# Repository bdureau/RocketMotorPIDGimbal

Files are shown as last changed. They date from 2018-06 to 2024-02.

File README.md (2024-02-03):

# RocketMotorPIDGimbal (firmware)
This is yet again another attempt to fly a model rocket without fins using long burn motors. The following repository is the firmware for the board.
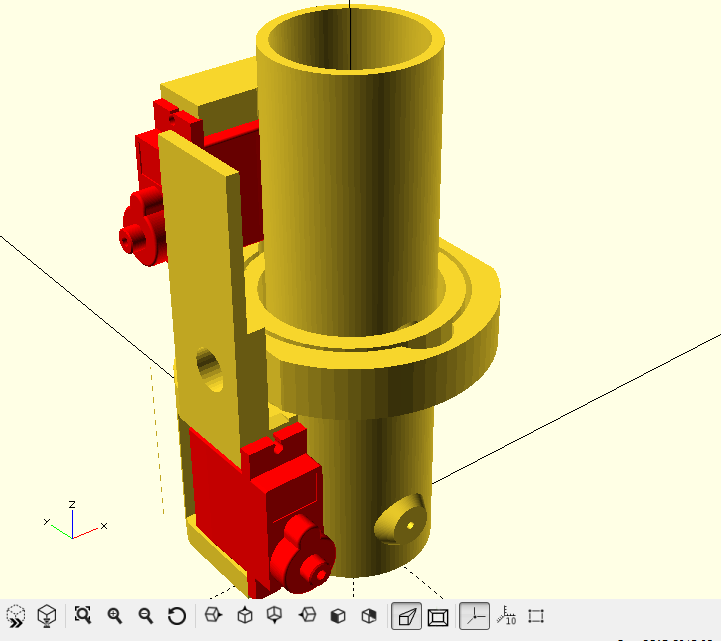
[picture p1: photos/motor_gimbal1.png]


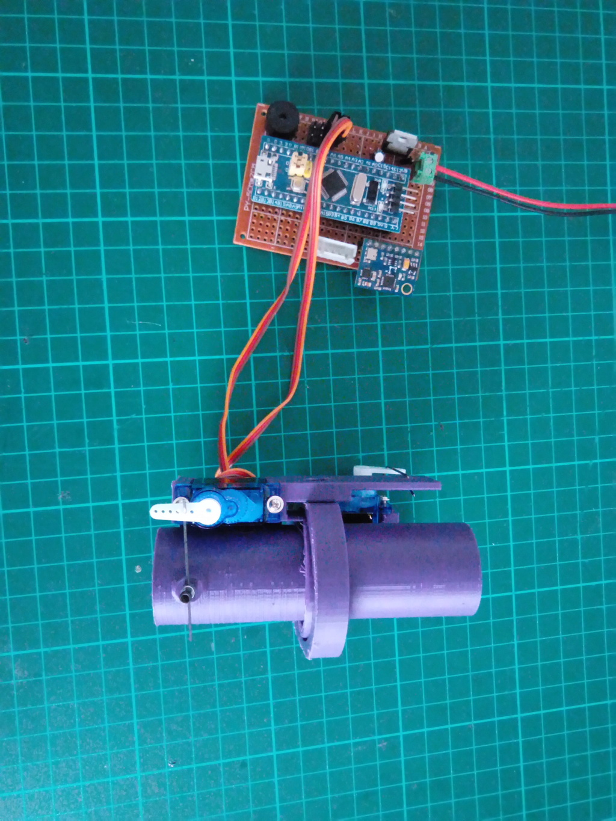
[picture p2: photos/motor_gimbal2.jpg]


I am using the Arduino PID library an STM32F103C board (you can use an arduino Nano) and a 3D printer to print the 24mm motor gimbal
It uses a bluetooth module (HC-05, HC-06 etc ...)to communicate with an Android device



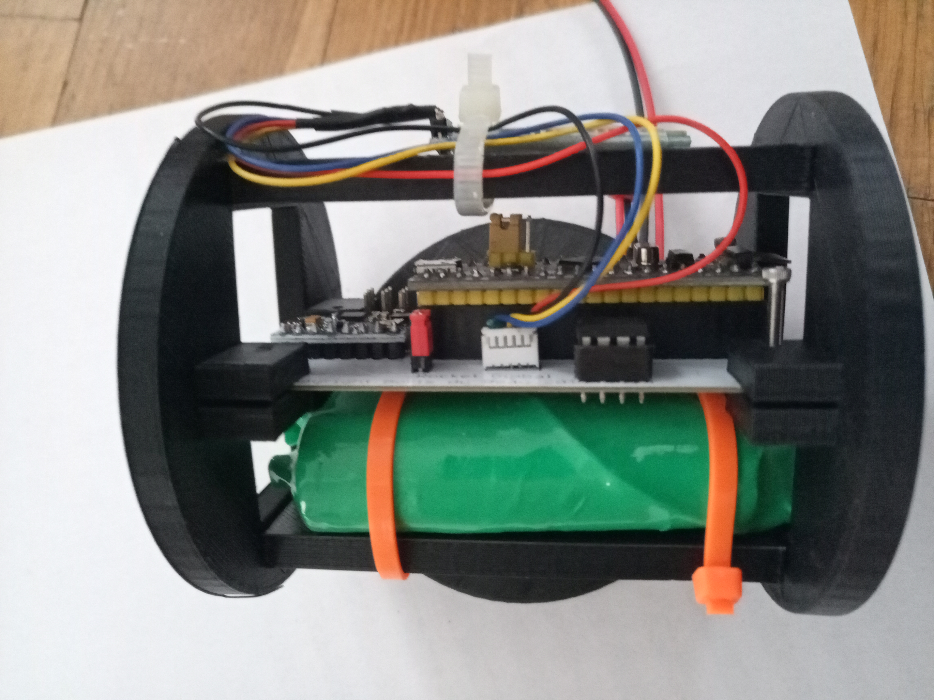
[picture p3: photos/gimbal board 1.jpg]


Use it with my Gimbal console application
https://github.com/bdureau/MotorGimbalConsole

I also have another version with the Bosch BNO055 sensor which is a lot less complex
https://github.com/bdureau/RocketMotorPIDGimbal_bno055/

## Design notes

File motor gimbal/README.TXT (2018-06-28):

Those are the files that need to be 3D printed. They can deal with a 24mm motor mount.
Plan is to improve them and use small bearing so that it can be used for 29mm or 38mm model rocket motor

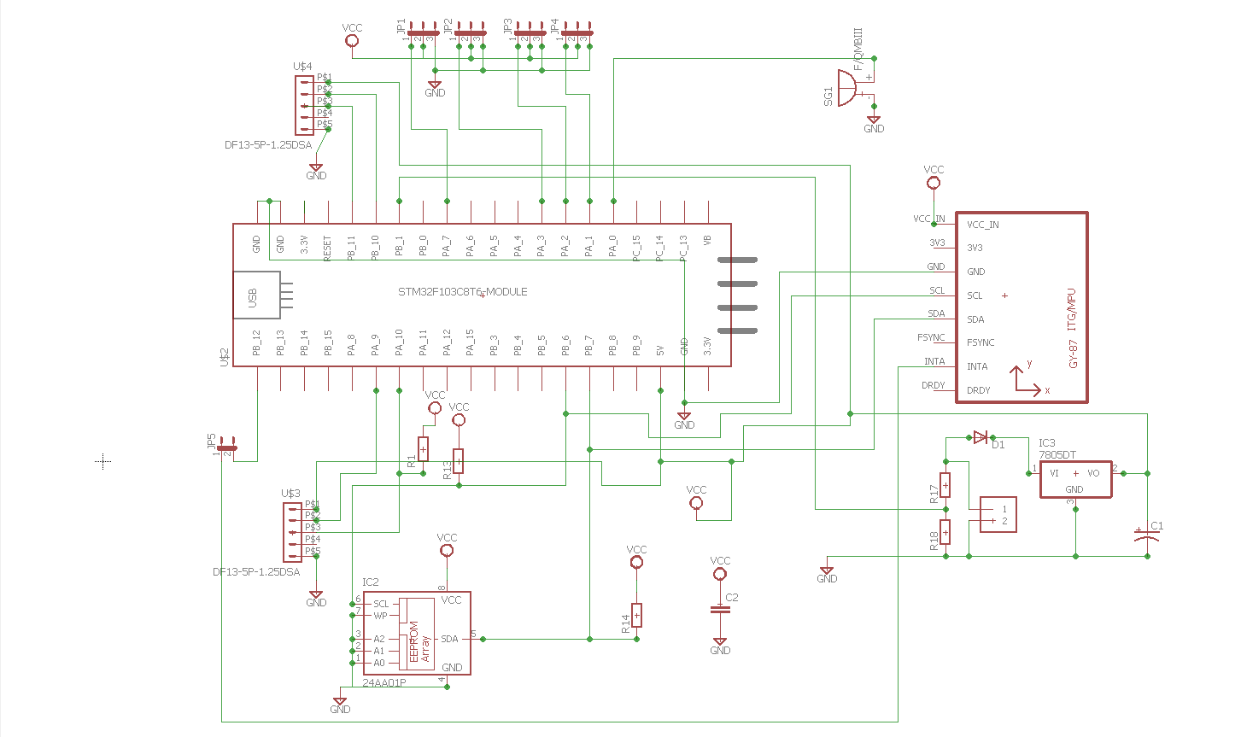
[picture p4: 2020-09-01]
gimbal schema/gimbal schema.png

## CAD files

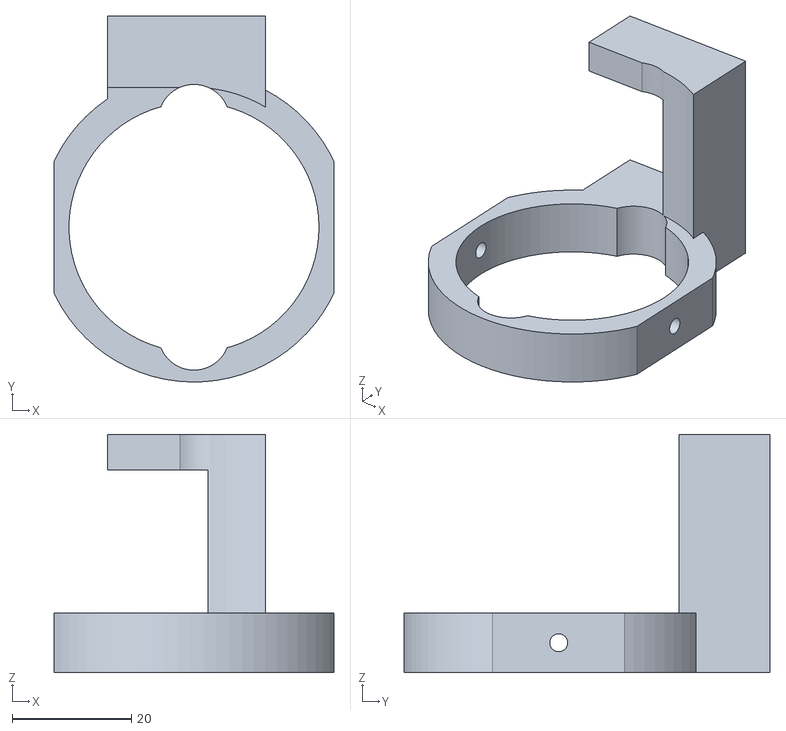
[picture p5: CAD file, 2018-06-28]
motor gimbal/motor gimbal 2.stl
47.0 x 61.5 x 40.0

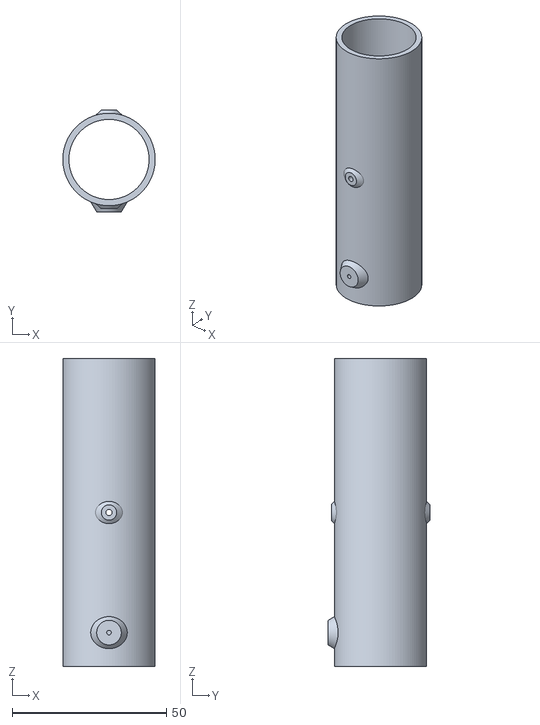
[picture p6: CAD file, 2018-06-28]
motor gimbal/motor tube.stl
30.0 x 33.0 x 100.0

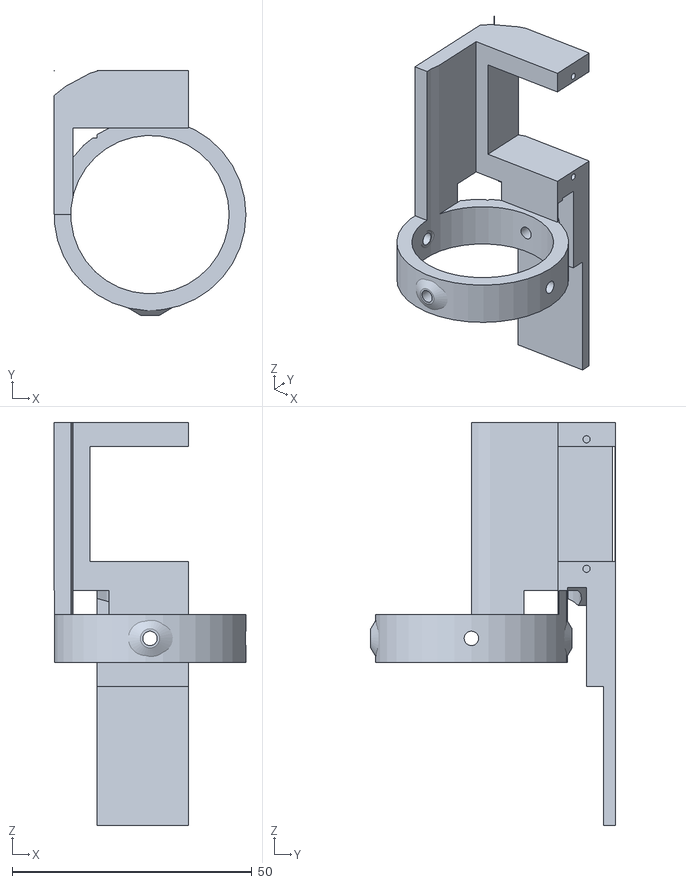
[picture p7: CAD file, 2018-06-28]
motor gimbal/motor gimbal 1.stl
40.0 x 51.0 x 84.0

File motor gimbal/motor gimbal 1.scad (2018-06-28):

$fn =35;

innerDiam = 33;
outterDiam = 40;
union() {difference() {
    union() {
        cylinder( r = outterDiam/2, h = 10);
        translate([-outterDiam/2,0,-34]) cube([(outterDiam/2)+8, 30, 84]);
        
        //bout
        translate ([20,0 , 5])rotate([90,90,0])bout();
        translate ([-20, 0, 5])rotate([-90,90,0])bout();
    }
    translate ([0,0, -45]) cylinder( r = 46/2, h = 45);
    cylinder( r = innerDiam/2, h = 140);
    //bout
    translate ([innerDiam/2, 0, 5])rotate([90,90,0])bout();
    translate ([-innerDiam/2, 0, 5])rotate([-90,90,0])bout();
    //holes
    #translate ([-50, 0, 5]) rotate([90,0,90])cylinder(r=3/2, h= 100);
    #translate ([-0, -50, 5])rotate([0,90,90])cylinder(r=3/2, h= 100);
    
     #translate ([-0, 20, 5])rotate([0,90,90])cylinder(r=8/2, h= 20);
    
    //servo
   #translate([-(innerDiam/2 -4),(innerDiam/2)-2,21])cube([22,16,24]);
    #translate([-16,0,10])cube([25,18,40]);
    translate ([0,0, -25]) difference() {
    cylinder ( r = 36, h = 100);
       cylinder ( r = 32, h = 100);
    }
    //servo holes
    # translate([10,24,19.5])rotate([0,-90,0])cylinder(r=1.5/2, h = 10);
    translate([10,24,46.5])rotate([0,-90,0])cylinder(r=1.5/2, h = 10);
    //outer gim
    #difference() {
        cylinder(r=46/2, h =15);
        cylinder(r=outterDiam/2 , h=15);
        }
    
    #translate([-20,20,-40])cube([30,4,50]);
        #rotate([0,15,0])translate([-25,20,-30])cube([30,4,40]);
        #rotate([0,-15,0])translate([-5,20,-27])cube([30,4,40]);
        #translate([-22,11,-35])cube([6,30,50]);
        #translate([-17,16,-35])cube([6,30,50]);
        #translate([-18,22.5,-35])cube([30,5,30]);
     
    
}

//bout
        //translate ([20,0 , 5])rotate([90,90,0])bout();
        //translate ([-20, 0, 5])rotate([-90,90,0])bout();


    translate ([0,(outterDiam/2)+1 , 5])rotate([0,90,0])bout();
    translate ([0, -((outterDiam/2)+1), 5])rotate([-180,90,0])bout();
    


}

module bout() {
    difference() {
rotate([90,0,0]) cylinder (r1= 4/2, r2 =7, h = 3);
        #rotate([90,0,0])translate([-9,-6,0])cube([4,14, 5]);
        #rotate([90,0,0])translate([5,-6,0]) cube([4,12, 5]);
        rotate([90,0,0]) cylinder (r= 3/2,  h = 10);
        
    }
}
//bout();

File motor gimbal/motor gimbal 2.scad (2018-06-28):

$fn=75;
innerDiam = 42;
outterDiam=47;
outterDiam1=52;
difference () {
    union () {cylinder(r=outterDiam1/2, h=10); 
        translate([-outterDiam/2+9,0,0]) cube([outterDiam/2+3, outterDiam/2 +12, 40]);
    }
    cylinder(r=innerDiam/2, h=100, center = true); 
    translate([0,0,10])cylinder(r=outterDiam/2, h=100); 
    translate([-outterDiam/2,0,10])cube([outterDiam/2, outterDiam/2 , 44]);
    #translate([-((innerDiam/2)-6),outterDiam/2,10])cube([20,12,24]);
    
    //holes
    #translate ([-50, 0, 5]) rotate([90,0,90])cylinder(r=3/2, h= 100);
   
    //servo holes
    # translate([-11,28,8.5])rotate([0,-90,0])cylinder(r=1.5/2, h = 4);
    #translate([-11,28,35.5])rotate([0,-90,0])cylinder(r=1.5/2, h = 4);
    #difference() {
        
        cube([outterDiam1,outterDiam1,20], center=true);
    cube([outterDiam,outterDiam1,20], center=true);
    }
    #translate([0,18,0]) cylinder (r= 6, h =80, center = true);
    
    #translate([0,-18,0]) cylinder (r= 6, h =80, center = true);
    
    //outer gim
   /* #difference() {
        cylinder(r=82/2, h =10);
        cylinder(r=outterDiam1/2 , h=10);
        }*/
}

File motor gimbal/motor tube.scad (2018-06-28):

$fn=100;
difference() {
union() {
    cylinder(r=30/2, h =100);
    //bottom hole
    #translate ([0, -12, 11])rotate([90,0,0]) cylinder (r1= 7, r2 =4, h = 5);
    #translate ([0, -12, 50])rotate([90,0,0]) cylinder (r1= 7, r2 =5/2, h = 4);
    #translate ([0, 16, 50])rotate([90,0,0]) cylinder (r1= 5/2, r2 =7, h = 4);
}
cylinder(r=26/2, h =100);
    #translate([0,25,50])rotate([90,0,0]) cylinder (r= 2/2, h = 50);
#translate ([0, -10, 11])rotate([90,0,0]) cylinder (r= 1.5/2, h = 10);
}    

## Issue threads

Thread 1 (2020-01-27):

Problem with installing the libraries.

Monses34, 2020-01-27:
Is there a way to load the whole project onto Arduino?

bdureau, 2020-01-27:
Yes, you need first to install the stm32 arduino board so that you can compile it.
you might be able to use other Arduino board but you might have to modify the code.
So first let me know which board you are using.

neilferreri, 2020-10-13:
Do you have a link to the `BMP085_stm32.h` source?
I couldn't compile with the adafruit library either.
Thanks!

bdureau, 2020-10-15:
Yes you can find it here

https://github.com/bdureau/AltimetersLibs

 �

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

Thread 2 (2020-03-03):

Arduino Environment Error when compiling

BobCat-Space, 2020-03-03:
Hi,
When I go to compile the script I get this error and there is no solutions on the internet..
#error "Please select first the target STM32F10x device used in your application (in stm32f10x.h file)"
Is there a solution for this?
Thanks for your time,
Jack

bdureau, 2020-03-03:
Hello

Did you install the STM32 harware  support from Roger Clark?

 <https://www.rogerclark.net/category/stm32/page/2/> https://www.rogerclark.net/category/stm32/page/2/

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

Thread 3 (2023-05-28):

Usage of DMP on MPU6050

Blaschuko, 2023-05-28:
Hey!
I've noticed you're using DMP to get the rotation of the rocket, but I've read that it's pretty unreliable when using it with rockets (as it uses Earth's gravity to fuse sensor data). Have you encountered any inaccurate readings while testing it with a rocket?
Thanks for the help!

bdureau, 2023-05-29:
Hello
Good question. I sometime see the rocket jump and we might need a bit of filtering but I guess it is accurate enough for what we are doing.
Result that I get with the bno055 seam a lot better than the MPU6050.
Anyway I will be moving to other sensors soon
Regards
Boris

DeÂ : Blas Kozicki ***@***.***
EnvoyÃ©Â : 29 May 2023 01:45
Ã€Â : bdureau/RocketMotorPIDGimbal
CcÂ : Subscribed
ObjetÂ : [bdureau/RocketMotorPIDGimbal] Usage of DMP on MPU6050 (Issue #3)

Hey!
I've noticed you're using DMP to get the rotation of the rocket, but I've read that it's pretty unreliable when using it with rockets (as it uses Earth's gravity to fuse sensor data). Have you encountered any inaccurate readings while testing it with a rocket?
Thanks for the help!
—
Reply to this email directly,  <https://github.com/bdureau/RocketMotorPIDGimbal/issues/3> view it on GitHub, or  <https://github.com/notifications/unsubscribe-auth/AATGSHYSP4ZMFODBD4AIVEDXIPPPLANCNFSM6AAAAAAYSEPEMM> unsubscribe.
You are receiving this because you are subscribed to this thread.https://github.com/notifications/beacon/AATGSH3XADKFEGB6UGDA7ALXIPPPLA5CNFSM6AAAAAAYSEPEMOWGG33NNVSW45C7OR4XAZNFJFZXG5LFVJRW63LNMVXHIX3JMTHGOGPSMM.gifMessage ID: < <mailto:> ***@***.***>

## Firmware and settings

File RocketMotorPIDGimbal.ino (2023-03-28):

/*

   Description: Model Rocket motor gimbal using 2 servo. This is yet again another attempt to fly a model rocket without fins using long burn motors.
                It is using the Arduino PID controler to move a rocket motor.
                Angle changes can be monitored using a USB cable or a bluetooth interface
                Inspired by various camera gimbal projects
   Author: Boris du Reau
   Date: June 2018-2023
   Sensor used is an MPU6050 board

   You can use an Arduino Uno/Nano or stm32F103C board

   Servo Connection
   BROWN - gnd
   red - 5v
   yellow - d10 (pwm for Sero X) or PA1 for stm32
          - d11 (servo Y) or PA2 for stm32

   MPU board Connection
   VCC - 5v
   GND - GND
   SCL - A5  or pin SCL on the stm32
   SDA - A4  or pin SDA on the stm32
   INT - D2 (not used)

  This can be configured using the Gimbale Android application
  which is also hosted on Github
  Version 1.0:
  Can log the data from all sensors on the eeprom and comunicate with an Android device
  via the serial port or a bluetooth module.
  Version 1.1
  Configure the accelero and gyro range
  Fixes, added checksum
  Version 1.2
  Fixes
  Version 1.3
  Fixes adding additionnal param for the telemetry module
   Adding the BMP280 sensor
*/


#include "config.h"
#include "global.h"
#include "utils.h"
#include "kalman.h"
#include "logger_i2c_eeprom.h"
logger_I2C_eeprom logger(0x50) ;
long endAddress = 65536;
// current file number that you are recording
int currentFileNbr = 0;

// EEPROM start adress for the flights. Anything before that is the flight index
long currentMemaddress = 200;
boolean liftOff = false;
//boolean landed = true;
boolean rocketLanded = false;
boolean rocketApogee = false;
//ground level altitude
long initialAltitude;
long liftoffAltitude = 20;
long lastAltitude;
long apogeeAltitude;
//current altitude
long currAltitude;
bool canRecord;
bool recording = false;
bool rec = false;
unsigned long initialTime = 0;
unsigned long prevTime = 0;
unsigned long diffTime;
unsigned long currentTime = 0;
//nbr of measures to do so that we are sure that apogee has been reached
unsigned long measures = 5;
long recordingTimeOut = 20000;
long lastBattWarning = 0;

/*
   ReadAltitude()
   Read altitude and filter any nose with a Kalman filter
*/
/*double ReadAltitude()
{
  return KalmanCalc(bmp.readAltitude());
}*/

#ifdef BMP085_180
/*
   ReadAltitude()
   Read Altitude function for a BMP85 or 180 Bosch sensor

*/
double ReadAltitude()
{
  return KalmanCalc(bmp.readAltitude());
  //return bmp.readAltitude();
}
#endif

#ifdef BMP280
/*

   Read Altitude function for a BMP280 Bosch sensor


*/
double ReadAltitude()
{
  /*double T, P, A;
  char result = bmp.startMeasurment();
  if (result != 0) {
    delay(result);
    result = bmp.getTemperatureAndPressure(T, P);
    A = KalmanCalc(bmp.altitude(P, P0));
  }
  return A;*/
  return KalmanCalc(bmp.readAltitude(1013.25));
  
  
  
}
#endif

// ================================================================
// ===               INTERRUPT DETECTION ROUTINE                ===
// ================================================================

volatile bool mpuInterrupt = false;     // indicates whether MPU interrupt pin has gone high
void dmpDataReady() {
  mpuInterrupt = true;
}

/*
   Initial setup
    do the board calibration
    if you use the calibration function do not move the board until the calibration is complete

*/
void setup()
{
  pinMode(pinSpeaker, OUTPUT);
  digitalWrite(pinSpeaker, LOW);
  beepAltiVersion(MAJOR_VERSION, MINOR_VERSION);
  ax_offset = 1118;
  ay_offset = 513;
  az_offset = 1289;
  gx_offset = 64;
  gy_offset = -1;
  gz_offset = -33;
  ServoX.attach(PA1);  // attaches the X servo on PA1 for stm32 or D10 for the Arduino Uno
  ServoY.attach(PA2);  // attaches the Y servo on PA2 for stm32 or D11 for the Arduino Uno

  // set both servo's to 90 degree
  ServoX.write(90);
  ServoY.write(90);
  delay(500);

  Wire.begin();
  //default values
  //defaultConfig();
  // Read altimeter softcoded configuration
  boolean softConfigValid = false;
  softConfigValid = readAltiConfig();

  // check if configuration is valid
  if (!softConfigValid)
  {
    //default values
    defaultConfig();
    /*#ifdef SERIAL_DEBUG
        Serial1.println(F("Config invalid"));
        Serial1.println("ax_offset =" + config.ax_offset);
        Serial1.println("ay_offset =" + config.ay_offset);
        Serial1.println("az_offset =" + config.az_offset);
        Serial1.println("gx_offset =" + config.gx_offset);
        Serial1.println("gy_offset =" + config.gy_offset);
        Serial1.println("gz_offset =" + config.gz_offset);
      #endif*/
    //delay(1000);
    //calibrate();
    config.ax_offset = ax_offset;
    config.ay_offset = ay_offset;
    config.az_offset = az_offset;
    config.gx_offset = gx_offset;
    config.gy_offset = gy_offset;
    config.gz_offset = gz_offset;
    writeConfigStruc();
  }
  Serial1.begin(38400);
  while (!Serial1);      // wait for Leonardo enumeration, others continue immediately

  bmp.begin( config.altimeterResolution);

  // init Kalman filter
  KalmanInit();
  // let's do some dummy altitude reading
  // to initialise the Kalman filter
  for (int i = 0; i < 50; i++) {
    ReadAltitude();
  }

  long sum = 0;
  for (int i = 0; i < 10; i++) {
    sum += ReadAltitude(); //bmp.readAltitude();
    delay(50);
  }
  initialAltitude = (sum / 10.0);

  // configure LED for output
  pinMode(LED_PIN, OUTPUT);
  pinMode(INTERRUPT_PIN, INPUT);



  // INPUT CALIBRATED OFFSETS HERE; SPECIFIC FOR EACH UNIT AND EACH MOUNTING CONFIGURATION!!!!
  // use the calibrate function for yours
  // you can also write down your offset and use them so that you do not have to re-run the calibration
  ax_offset = config.ax_offset;
  ay_offset = config.ay_offset;
  az_offset = config.az_offset;
  gx_offset = config.gx_offset;
  gy_offset = config.gy_offset;
  gz_offset = config.gz_offset;

  Serial1.println("init device");
  //Initialize MPU
  initialize();

  // Get flight
  int v_ret;
  v_ret = logger.readFlightList();
  //int epromsize = logger.determineSize();
  //Serial1.println(epromsize);
  long lastFlightNbr = logger.getLastFlightNbr();

  if (lastFlightNbr < 0)
  {
    currentFileNbr = 0;
    currentMemaddress = 201;
  }
  else
  {
    currentMemaddress = logger.getFlightStop(lastFlightNbr) + 1;
    currentFileNbr = lastFlightNbr + 1;
  }
  canRecord = logger.CanRecord();
  //canRecord = true;
  recordingTimeOut = config.recordingTimeout * 1000;
}

/*

   Initialize the MUP6050 sensor

*/
void initialize() {
  // verify connection
#ifdef SERIAL_DEBUG
  Serial1.println(F("Testing device connections..."));
  Serial1.println(mpu.testConnection() ? F("MPU6050 connection successful") : F("MPU6050 connection failed"));
#endif
  // initialize device
  // do not use the constructor so that we can change the gyro and ACCEL RANGE
  // values accelerometer are:
  // MPU6050_ACCEL_FS_2
  // MPU6050_ACCEL_FS_4
  // MPU6050_ACCEL_FS_8
  // MPU6050_ACCEL_FS_16
  // Values for the Gyro are:
  // MPU6050_GYRO_FS_250
  // MPU6050_GYRO_FS_500
  // MPU6050_GYRO_FS_1000
  // MPU6050_GYRO_FS_2000

#ifdef SERIAL_DEBUG
  Serial1.println(F("Initializing MPU 6050 device..."));
#endif
  mpu.setClockSource(MPU6050_CLOCK_PLL_XGYRO);
  //mpu.setFullScaleGyroRange(MPU6050_GYRO_FS_250);
  // mpu.setFullScaleAccelRange(MPU6050_ACCEL_FS_2);
  mpu.setFullScaleGyroRange(config.gyroRange);
  mpu.setFullScaleAccelRange(config.acceleroRange);
  mpu.setSleepEnabled(false); // thanks to Jack Elston for pointing this one out!

  // load and configure the DMP
#ifdef SERIAL_DEBUG
  Serial1.println(F("Initializing DMP"));
#endif
  mpu.initialize(); //added
  devStatus = mpu.dmpInitialize();
  mpu.setXAccelOffset(ax_offset);
  mpu.setYAccelOffset(ay_offset);
  mpu.setZAccelOffset(az_offset);
  mpu.setXGyroOffset(gx_offset);
  mpu.setYGyroOffset(gy_offset);
  mpu.setZGyroOffset(gz_offset);
  //turn the PID on
  //servo's can go from 60 degree's to 120 degree so set the angle correction to + - 30 degrees max
  myPIDX.SetOutputLimits(-5, 5);
  myPIDY.SetOutputLimits(-5, 5);
  myPIDX.SetMode(AUTOMATIC);
  myPIDY.SetMode(AUTOMATIC);
  SetpointX = 0;
  SetpointY = 0;
  // make sure it worked (returns 0 if so)
  if (devStatus == 0)
  {
    // turn on the DMP, now that it's ready
#ifdef SERIAL_DEBUG
    Serial1.println(F("Enabling DMP"));
#endif
    mpu.setDMPEnabled(true);
    attachInterrupt(digitalPinToInterrupt(INTERRUPT_PIN), dmpDataReady, RISING);
    mpuIntStatus = mpu.getIntStatus();
    dmpReady = true;
    // get expected DMP packet size for later comparison
    packetSize = mpu.dmpGetFIFOPacketSize();
  }
  else
  {
    // ERROR!
    // 1 = initial memory load failed, 2 = DMP configuration updates failed (if it's going to break, usually the code will be 1)
#ifdef SERIAL_DEBUG
    Serial1.print(F("DMP Initialization failed code = "));
    Serial1.println(devStatus);
#endif
  }
}



/*

   MAIN PROGRAM LOOP

*/
void loop(void)
{
  MainMenu();
}

void Mainloop(void)
{
  long startTime = millis();

  //read current altitude
  currAltitude = (ReadAltitude() - initialAltitude);
  bool lift = false;
  if (config.liftOffDetect == 0) { //use baro detection
    if ( currAltitude > liftoffAltitude)
      lift = true;
  }
  else { // use accelero
    if (mpu.getAccelerationY() > 30000)
      lift = true;
  }

  if ((lift && !liftOff) || (recording && !liftOff))
  {

    //#ifdef SERIAL_DEBUG
    //Serial1.println(F("start recording"));
//#endif
    liftOff = true;
    rocketLanded = false;
    rocketApogee = false;
    if (recording)
      rec = true;
    // save the time
    initialTime = millis();
    prevTime = 0;
    if (canRecord)
    {
      long lastFlightNbr = logger.getLastFlightNbr();

      if (lastFlightNbr < 0)
      {
        currentFileNbr = 0;
        currentMemaddress = 201;
      }
      else
      {
        //#ifdef SERIAL_DEBUG
   // Serial1.println(F("currentMemaddress"));
//#endif
        currentMemaddress = logger.getFlightStop(lastFlightNbr) + 1;
        currentFileNbr = lastFlightNbr + 1;
      }
      //Save start address
      logger.setFlightStartAddress (currentFileNbr, currentMemaddress);
    }
    //Serial1.println("We have a liftoff");
  }
  if (canRecord && liftOff)
  {
    //#ifdef SERIAL_DEBUG
    //Serial1.println(F("canRecord && liftOff"));
//#endif
    currentTime = millis() - initialTime;
    diffTime = currentTime - prevTime;
    prevTime = currentTime;
    logger.setFlightTimeData( diffTime);
    logger.setFlightAltitudeData((long) currAltitude);
    logger.setFlightTemperatureData((long) bmp.readTemperature());
    logger.setFlightPressureData((long) bmp.readPressure());

    float w = q.w;
    float x = q.x;
    float y = q.y;
    float z = q.z;

    logger.setFlightRocketPos((long) (w * 1000), (long) (q.x * 1000), (long) (q.y * 1000), (long) (q.z * 1000));
    logger.setFlightCorrection( (long) OutputX, (long)OutputY);
    logger.setAcceleration(mpu.getAccelerationX(), mpu.getAccelerationY(), mpu.getAccelerationZ());
    if ( (currentMemaddress + logger.getSizeOfFlightData())  > endAddress) {
      //flight is full let save it
      //save end address
      logger.setFlightEndAddress (currentFileNbr, currentMemaddress - 1);
      canRecord = false;
    } else {
       //#ifdef SERIAL_DEBUG
    //Serial1.println(F("writting"));
    delay(10);
    //Serial1.println(currentMemaddress);
//#endif
      currentMemaddress = logger.writeFastFlight(currentMemaddress);
      currentMemaddress++;
    }
  }

  //detect apogee
  if (liftOff) {
    if (currAltitude < lastAltitude  )
    {
      measures = measures - 1;
      if (measures == 0)
      {
        //apogeeAltitude = currAltitude;
        apogeeAltitude = lastAltitude;
        rocketApogee = true;
      }
    }
    else
    {
      lastAltitude = currAltitude;
      //number of measures to do to detect Apogee
      measures = 5; //= config.nbrOfMeasuresForApogee;
    }
  }

  // if (((canRecord && currAltitude < 10) && liftOff && !recording && !rec) || (!recording && rec))
  if (((canRecord && currAltitude < 10) && liftOff && !recording && !rec) || (!recording && rec) || (canRecord && liftOff && !recording && !rec && (millis() - initialTime) > recordingTimeOut))
  {
    #ifdef SERIAL_DEBUG
    Serial1.println(F("finishing"));
    Serial1.println(currentFileNbr);
    #endif
    liftOff = false;
    rec = false;
    //end loging
    //store start and end address
    logger.setFlightEndAddress (currentFileNbr, currentMemaddress - 1);
    logger.writeFlightList();
    if ((millis() - initialTime) > recordingTimeOut)
      canRecord = false;
  }

  if ((currAltitude < 10) && rocketApogee && !recording && !rec) {
    //landed
    rocketLanded = true;
    //SendTelemetry(q1, 200);
  }

  /////////

  // wait for MPU interrupt or extra packet(s) available
  while (!mpuInterrupt && fifoCount < packetSize) {
    if (mpuInterrupt && fifoCount < packetSize) {
      // try to get out of the infinite loop
      fifoCount = mpu.getFIFOCount();
    }
  }

  // reset interrupt flag and get INT_STATUS byte
  mpuInterrupt = false;
  mpuIntStatus = mpu.getIntStatus();

  // get current FIFO count
  fifoCount = mpu.getFIFOCount();

  // check for overflow (this should never happen unless our code is too inefficient)
  if ((mpuIntStatus & _BV(MPU6050_INTERRUPT_FIFO_OFLOW_BIT)) || fifoCount >= 1024) {
    // reset so we can continue cleanly
    mpu.resetFIFO();
    fifoCount = mpu.getFIFOCount();
#ifdef SERIAL_DEBUG
    Serial1.println(F("FIFO overflow!"));
#endif
    // otherwise, check for DMP data ready interrupt (this should happen frequently)
  } else if (mpuIntStatus & _BV(MPU6050_INTERRUPT_DMP_INT_BIT)) {
    // wait for correct available data length, should be a VERY short wait
    while (fifoCount < packetSize) fifoCount = mpu.getFIFOCount();

    // read a packet from FIFO
    mpu.getFIFOBytes(fifoBuffer, packetSize);

    // track FIFO count here in case there is > 1 packet available
    // (this lets us immediately read more without waiting for an interrupt)
    fifoCount -= packetSize;

    // display Euler angles in degrees
    mpu.dmpGetQuaternion(&q, fifoBuffer);
    //mpu.dmpGetAccel(&aa, fifoBuffer);
    mpu.dmpGetGravity(&gravity, &q);
    mpu.dmpGetYawPitchRoll(ypr, &q, &gravity);
    mpuPitch = ypr[PITCH] * 180 / M_PI;
    mpuRoll = ypr[ROLL] * 180 / M_PI;
    mpuYaw  = ypr[YAW] * 180 / M_PI;

    /*mpuRoll = -ypr[ROLL] * 180 / M_PI;
      mpuYaw  = -ypr[YAW] * 180 / M_PI;*/

    // flush buffer to prevent overflow
    mpu.resetFIFO();
  }
  // blink LED to indicate activity
  blinkState = !blinkState;
  digitalWrite(LED_PIN, blinkState);

  // flush buffer to prevent overflow
  mpu.resetFIFO();
  InputX = mpuPitch;
  myPIDX.Compute();
  InputY = mpuRoll;
  myPIDY.Compute();

  //if using PID do those
  //ServoX.write(-OutputX + 90);
  //ServoY.write(OutputY + 90);

  // if you do not want to use the PID
  /* ServoX.write(-mpuPitch + 90);
    ServoY.write(mpuRoll + 90);*/
  int SX = -mpuPitch + 180;
  if (SX < 80)
    SX = 80;
  if (SX > 100)
    SX = 100;
  int SY = mpuYaw + 90;

  if (SY < 80)
    SY = 80;
  if (SY > 100)
    SY = 100;

  ServoX.write(SX);
  ServoY.write(SY);
  /*delay(10);*/


  float q1[4];
  //mpu.dmpGetQuaternion(&q, fifoBuffer);

  q1[0] = q.w;
  q1[1] = q.x;
  q1[2] = q.y;
  q1[3] = q.z;

  //serialPrintFloatArr(q1, 4);
  currentTime = millis() - initialTime;
  SendTelemetry(q1, 200);
  checkBatVoltage(BAT_MIN_VOLTAGE);

  if (!liftOff) // && !canRecord)
    delay(10);

  // flush buffer to prevent overflow
  mpu.resetFIFO();
}




//================================================================
// Main menu to interpret all the commands sent by the altimeter console
//================================================================
void MainMenu()
{
  char readVal = ' ';
  int i = 0;

  char commandbuffer[1000] = "";


  while ( readVal != ';') {
    if (mainLoopEnable)
      Mainloop();
    while (Serial1.available())
    {
      readVal = Serial1.read();
      if (readVal != ';' )
      {
        if (readVal != '\n')
          commandbuffer[i++] = readVal;
      }
      else
      {
        commandbuffer[i++] = '\0';
        resetFlight();
        break;
      }
    }
  }

  interpretCommandBuffer(commandbuffer);
  for (int i = 0; i < sizeof(commandbuffer); i++)
    commandbuffer[i] = '\0';
}
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

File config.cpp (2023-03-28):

#include "config.h"
ConfigStruct config;
const int pinSpeaker = PA0;
//================================================================
// read and write in the microcontroler eeprom
//================================================================
void defaultConfig()
{
  config.ax_offset = 0;
  config.ay_offset = 0;
  config.az_offset = 0;
  config.gx_offset = 0;
  config.gy_offset = 0;
  config.gz_offset = 0;
  config.KpX = 0;
  config.KiX = 0;
  config.KdX = 0;
  config.KpY = 0;
  config.KiY = 0;
  config.KdY = 0;
  config.ServoXMin = 0;
  config.ServoXMax = 0;
  config.ServoYMin = 0;
  config.ServoYMax = 0;
  config.connectionSpeed = 38400;
  config.altimeterResolution = 0;
  config.eepromSize = 512;
  config.unit = 0;
  config.endRecordAltitude = 3;
  config.beepingFrequency = 440;
  config.liftOffDetect = 0;
  config.gyroRange = 0;
  config.acceleroRange = 0;
  config.recordingTimeout = 120;
  config.batteryType = 0; // 0= Unknown, 1= "2S (7.4 Volts)", 2 = "9 Volts",3 = "3S (11.1 Volts)
  config.telemetryType = 0;
  config.cksum = CheckSumConf(config);
}



boolean readAltiConfig() {
  //set the config to default values so that if any have not been configured we can use the default ones
  defaultConfig();
  int i;
  for ( i = 0; i < sizeof(config); i++ ) {
    *((char*)&config + i) = EEPROM.read(CONFIG_START + i);
  }

  if ( config.cksum != CheckSumConf(config) ) {

    return false;
  }

  return true;

}

/*
  write the config received by the console

*/
/*bool  writeAltiConfig( char *p ) {
  //Serial1.println(p);
  char *str;

  int i = 0;
  int strChk = 0;
  char msg[100] = "";
  while ((str = strtok_r(p, ",", &p)) != NULL) // delimiter is the comma
  {
    //Serial1.println(str);
    switch (i)
    {
      case 1:
        config.ax_offset = atoi(str);
        strcat(msg, str);
        break;
      case 2:
        config.ay_offset = atoi(str);
        strcat(msg, str);
        break;
      case 3:
        config.az_offset = atoi(str);
        strcat(msg, str);
        break;
      case 4:
        config.gx_offset = atoi(str);
        strcat(msg, str);
        break;
      case 5:
        config.gy_offset = atoi(str);
        strcat(msg, str);
        break;
      case 6:
        config.gz_offset = atoi(str);
        strcat(msg, str);
        break;
      case 7:
        config.KpX = atoi(str);
        strcat(msg, str);
        break;
      case 8:
        config.KiX = atoi(str);
        strcat(msg, str);
        break;
      case 9:
        config.KdX = atoi(str);
        strcat(msg, str);
        break;
      case 10:
        config.KpY = atoi(str);
        strcat(msg, str);
        break;
      case 11:
        config.KiY = atoi(str);
        strcat(msg, str);
        break;
      case 12:
        config.KdY = atoi(str);
        strcat(msg, str);
        break;
      case 13:
        config.ServoXMin = atoi(str);
        strcat(msg, str);
        break;
      case 14:
        config.ServoXMax = atoi(str);
        strcat(msg, str);
        break;
      case 15:
        config.ServoYMin = atoi(str);
        strcat(msg, str);
        break;
      case 16:
        config.ServoYMax = atoi(str);
        strcat(msg, str);
        break;
      case 17:
        config.connectionSpeed = atoi(str);
        strcat(msg, str);
        break;
      case 18:
        config.altimeterResolution = atoi(str);
        strcat(msg, str);
        break;
      case 19:
        config.eepromSize = atoi(str);
        strcat(msg, str);
        break;
      case 20:
        config.unit = atoi(str);
        strcat(msg, str);
        break;
      case 21:
        config.endRecordAltitude = atoi(str);
        strcat(msg, str);
        break;
      case 22:
        config.beepingFrequency = atoi(str);
        strcat(msg, str);
        break;
      case 23:
        config.liftOffDetect = atoi(str);
        strcat(msg, str);
        break;
      case 24:
        config.gyroRange = atoi(str);
        strcat(msg, str);
        break;
      case 25:
        config.acceleroRange = atoi(str);
        strcat(msg, str);
        break;
      case 26:
        config.recordingTimeout = atoi(str);
        strcat(msg, str);
        break;
      case 27:
        config.batteryType = atoi(str);
        strcat(msg, str);
        break;   
      case 28:
        //our checksum
        strChk = atoi(str);
        //strcat(msg, str);
        break;
    }
    i++;

  }

  //we have a partial config
  if (i < 27)
    return false;
  if (msgChk(msg, sizeof(msg)) != strChk)
    return false;
  //calculate checksum
  config.cksum = CheckSumConf(config);

  writeConfigStruc();
  return true;
}*/
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

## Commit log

2018-06-28 Add files via upload
    Initial upload
    [motor gimbal 1.scad, motor gimbal 2.scad, motor tube.scad]
2018-12-06 Add files via upload
    Added calibration and ability to send data to the Android application
2019-07-15 bug fixes and improvments
    [RocketMotorPIDGimbal.ino, config.cpp, logger_i2c_eeprom.cpp]
2019-07-24 Bug fixes for the quaternion
    [RocketMotorPIDGimbal.ino, logger_i2c_eeprom.cpp]
2020-02-06 Fixes when eeprom is empty
    [RocketMotorPIDGimbal.ino]
2020-02-06 Fixes to the battery voltage reading
    [RocketMotorPIDGimbal.ino, config.cpp]
2020-02-14 Added low battery detection and warning
2020-10-28 Added accelerometer and gyro ranges to the config
2020-11-08 Fixes to the config
    [RocketMotorPIDGimbal.ino, global.h]
2021-04-14 Fixes to the float
    [RocketMotorPIDGimbal.ino, global.h, logger_i2c_eeprom.cpp]
2021-05-25 fixes to the flight erase
    [RocketMotorPIDGimbal.ino]
2021-11-14 Fixes to the flight init
    [RocketMotorPIDGimbal.ino, logger_i2c_eeprom.cpp]
2022-01-25 Fixes to the config. Adding the bmp085 lib
    [Bear_BMP085.cpp, RocketMotorPIDGimbal.ino, config.cpp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]
